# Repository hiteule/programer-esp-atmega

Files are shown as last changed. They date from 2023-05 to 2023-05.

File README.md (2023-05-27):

# ESP / Atmega programmer

An electronic board designed to programm an ESP or an Atmega microcontroller.
The board is based on a FT32RL Serial Adapter module.

You need to switch the JP-RTS jumper to be able to programm the ESP or the Atmega.
You need to switch the voltage level of the Serial Adapter module to programm the ESP (3.3V) or the Atmega (5V).

The 3.3V power output of the Serial Adapter module is too weak to run the ESP.
You need to use an external power source between 3.3V and 12V through J1.
The Atmega is not concerned (powered through the USB / Serial Adapter module).

The card was designed with [Eagle].
The additional [libraries] used are:
* CONNECTORS.lbr
* regulator.lbr

[Eagle]:     https://www.autodesk.fr/products/eagle
[libraries]: https://github.com/hiteule/eagle-library

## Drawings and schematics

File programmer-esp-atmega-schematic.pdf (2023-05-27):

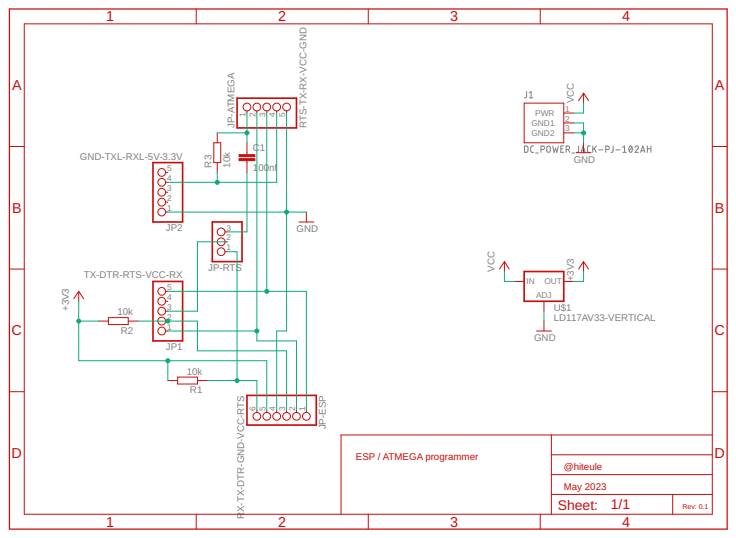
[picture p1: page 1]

RTS-TX-RX-VCC-GND TX-DTR-RTS-VCC-RX GND-TXL-RXL-5V-3.3V 100nf 10k 10k 10k RX-TX-DTR-GND-VCC-RTS LD117AV33-VERTICAL VCC GND GND VCC +3V3 +3V3 GND 12345 JP-ATMEGA 12345JP1 12345JP2 C1 R2 R3 R1 123 JP-RTS 654321 JP-ESP PWR 1 GND2 3 GND1 2 ADJ IN OUTU$1 ESP / ATMEGA programmer @hiteule May 2023 Sheet: Rev: 0.1 ABCD 1 2 3 4 ABCD 1 2 3 4 1/1

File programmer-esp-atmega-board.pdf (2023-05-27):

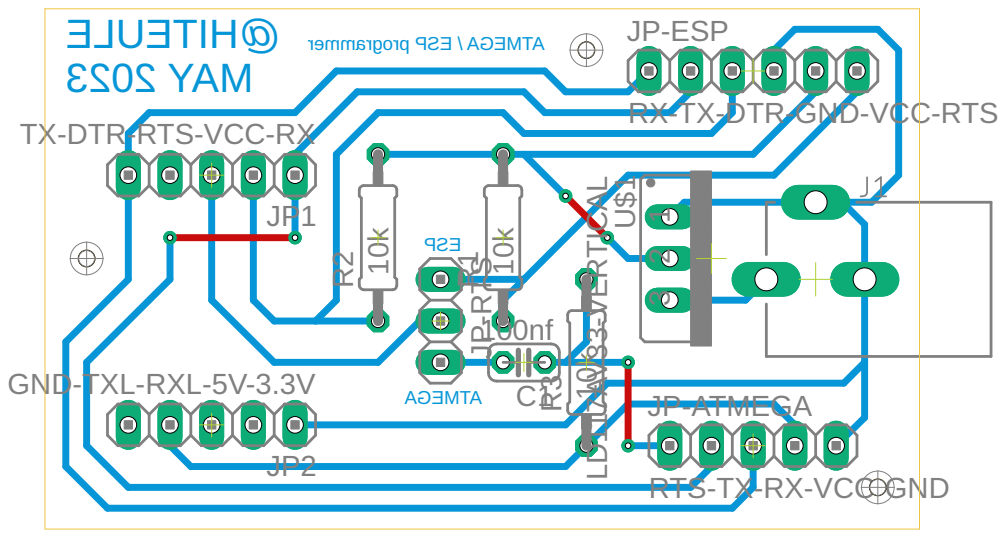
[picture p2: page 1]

10k 10k RX-TX-DTR-GND-VCC-RTS

TX-DTR-RTS-VCC-RX GND-TXL-RXL-5V-3.3V

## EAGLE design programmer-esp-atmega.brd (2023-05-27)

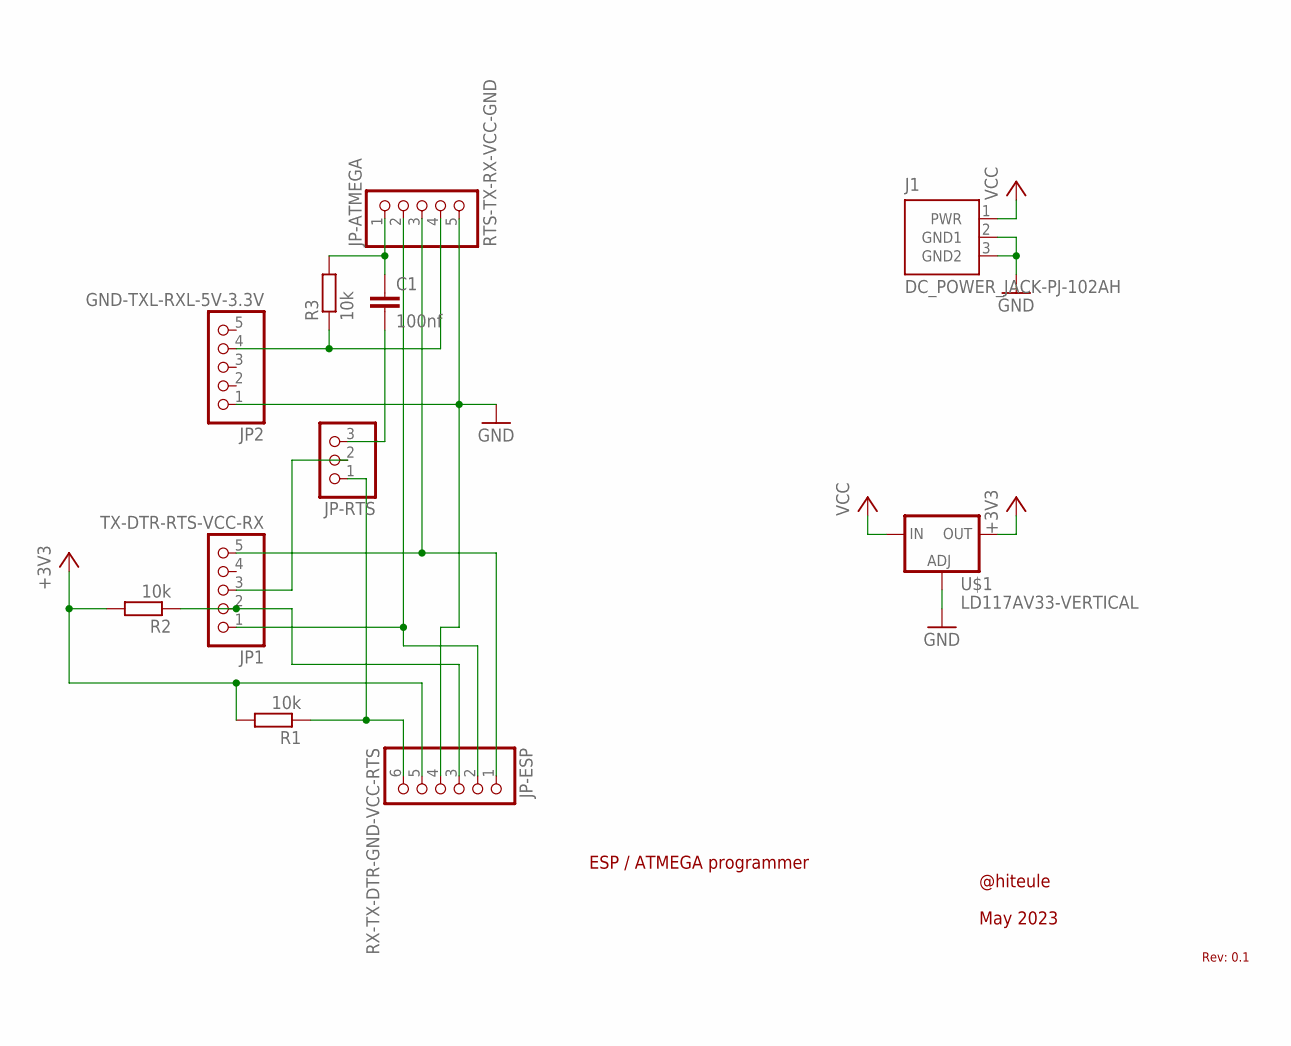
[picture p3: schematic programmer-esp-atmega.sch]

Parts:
C1: 100nf; C025-024X044
J1: DC_POWER_JACK-PJ-102AH; PJ-102AH
JP1: TX-DTR-RTS-VCC-RX; 1X05
JP2: GND-TXL-RXL-5V-3.3V; 1X05
JP-ATMEGA: RTS-TX-RX-VCC-GND; 1X05
JP-ESP: RX-TX-DTR-GND-VCC-RTS; 1X06
JP-RTS: PINHD-1X3; 1X03
R1, R2, R3: 10k; 0207/10
U$1: LD117AV33-VERTICAL; TO220S-VERTICAL

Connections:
+3V3: JP-ESP.5, R1.2, R2.2, U$1.2 (OUT)
GND: J1.2 (GND1), J1.3 (GND2), JP2.1, JP-ATMEGA.5, JP-ESP.4, U$1.1 (ADJ)
unnamed: JP2.4, JP-ATMEGA.4, R3.1
unnamed: JP1.5, JP-ATMEGA.3, JP-ESP.1
unnamed: JP1.1, JP-ATMEGA.2, JP-ESP.2
unnamed: C1.2, JP-RTS.3
unnamed: C1.1, JP-ATMEGA.1, R3.2
unnamed: JP1.3, JP-RTS.2
unnamed: JP-ESP.6, JP-RTS.1, R1.1
unnamed: JP1.2, JP-ESP.3, R2.1
VCC: J1.1 (PWR), U$1.3 (IN)

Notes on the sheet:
ESP / ATMEGA programmer
@hiteule
May 2023
Rev: 0.1

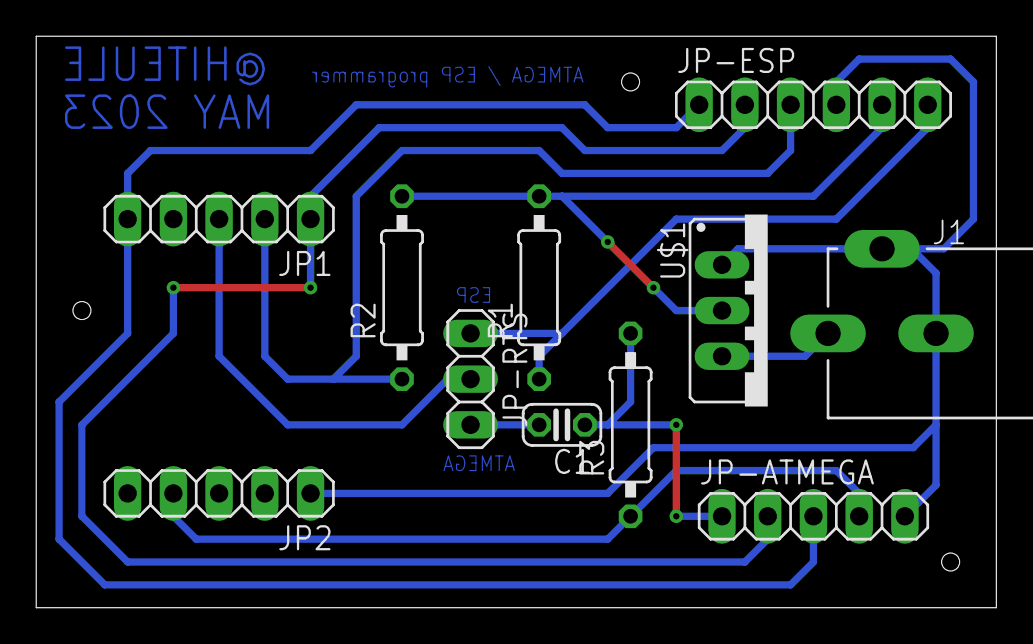
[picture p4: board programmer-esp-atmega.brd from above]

Board: 2 copper layers, 53.3 x 31.8 mm, 11 parts (0 on the bottom side), 11 nets.
